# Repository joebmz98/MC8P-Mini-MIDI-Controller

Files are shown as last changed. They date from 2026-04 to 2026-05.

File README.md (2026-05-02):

# MC8P Mini MIDI Controller

---

# **8-Pot Mini MIDI Controller**

A compact, open-source MIDI controller with **8 potentiometers**, each with **fully assignable MIDI CCs**, built for **Arduino NANO R3/R4 (Rev1)** or the **Pro Micro (Rev2)**.

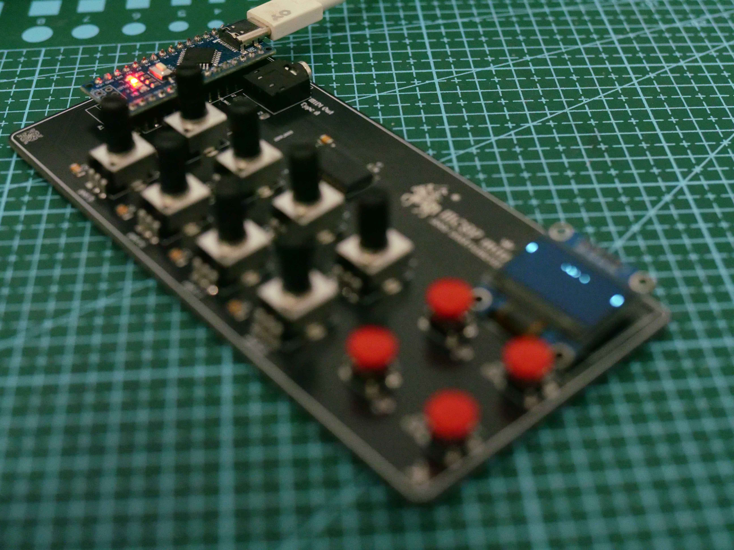
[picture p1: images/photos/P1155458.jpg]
Photo of the assembled MC8P mini MIDI Controller


---

## **Features**
- **8x Potentiometers** with smooth analog control via 16-channel MUX
- **Arduino NANO / Pro Micro (Rev2) Compatible** – Easy to source and program
- **SSD1306 I2C OLED (128x64)** for the UI
- **Per-Pot CC Assignment** – Full MIDI CC customization
- **4x Tactile Switches** for UI navigation/configuration
- **Standalone Operation** – No computer needed after setup
- **EEPROM Settings Storage** – Retains configurations after power-off
- **Temporary Override Mode** – Make temporary adjustments that snap back
- **MIDI over USB** (Pro Micro Rev ONLY) – Class-compliant, plug-and-play
- **Open-Source Firmware** (Arduino IDE-compatible)

---

## **Bill of Materials (BOM)**

| Component | Qty | Notes | Links / Part Numbers |
|---|-----|---|---|
| Arduino NANO / Pro Micro | 1 | Main microcontroller | [Arduino NANO R3](https://www.aliexpress.com/w/wholesale-arduino-nano.html?spm=a2g0o.productlist.search.0) / [Pro Micro](https://www.aliexpress.com/w/wholesale-pro-micro-arduino.html?spm=a2g0o.best.search.0) |
| 16-Channel MUX (74HC4067)  | 1 | For reading 8 potentiometers | [AliExpress](https://www.aliexpress.com/w/wholesale-cd74hc4067.html?spm=a2g0o.productlist.search.0) / CD74HC4067M96 (JLCPCB) |
| SSD1306 OLED (128×64) | 1 | I²C interface | [AliExpress](https://www.aliexpress.com/w/wholesale-ssd1306.html?spm=a2g0o.productlist.search.0) |
| B100K Potentiometers | 8 | Linear taper | [AliExpress](https://www.aliexpress.com/item/1005003523799166.html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"order"%3A"368"%2C"eval"%3A"1"%2C"fromPage"%3A"search"%7D&pdp_npi=6%40dis%21GBP%210.33%210.33%21%21%210.43%210.43%21%402151e6dc17777134792648341e4c8f%2112000026166615223%21sea%21UK%216042796089%21X%211%210%21n_tag%3A-29919%3Bd%3A582ad943%3Bm03_new_user%3A-29895&curPageLogUid=hZYrDWLC06u8&utparam-url=scene%3Asearch%7Cquery_from%3A%7Cx_object_id%3A1005003523799166%7C_p_origin_prod%3A&search_p4p_id=2026050202175910656752474918880005794025_1) |
| Tactile Switches | 4 | For menu navigation (ASSIGN, ENTER, PREV, NEXT) | K2-6639DP-B4SW-04 (JLCPCB) |
| 10k Resistors (SMD) | 7 | Pull-up for buttons and misc | 0603WAF1002T5E (JLCPCB) |
| 100nF SMD Capacitor | 1 | Power rail stabilisation | 1206B104K101CT (JLCPCB) |
| 10nF SMD Capacitors | 8 | Potentiometer filtering | 1206B103K500NT (JLCPCB) |
| 220Ω SMD Resistors | 2 | For MIDI circuitry | 0603WAF2200T5E (JLCPCB) |
| PJ307 Stereo Headphone Socket | 1 | 3.5mm MIDI TRS Out (Type A) | — |
| Reset Button (SMD) | 1 | Rev2 only - Reset button | KMR221GLFS (JLCPCB) |
| 0.1" Header Pins | 1 | For connecting components | — |
| PCB | 1 | Custom design | — |
| Potentiometer Knobs | 8 | For B100K potentiometers | — |

---

## **Available Purchase Options**
**DIY Kits** - Only NANO version (rev1) available → [**Purchase from my Tindie store**](https://www.tindie.com/stores/axsinstruments/)

---

## **Installation & Setup**
### **1. Flashing the Firmware**
- Install **Arduino IDE**
- Install required libraries (see Building from Source section)
- Open the `.ino` file in Arduino IDE | There are two files - one for NANO and one for Pro Micro
- Select your board (**Arduino NANO R3/R4 or ProMicro**)
- Upload the firmware

### **2. Hardware Assembly**
- Refer to the *Build Guide* (coming soon)

### **3. First Boot**
- Power via **USB** on the Arduino NANO
- Use the **OLED menu** to assign CCs

---

## **Configuration**

### Button Functions

| Button | Primary Function |
|---|---|
| ASSIGN | Enter/exit MIDI assignment menu |
| ENTER | Enter temporary override mode (hold), confirm selections |
| PREV | Decrease values, navigate up |
| NEXT | Increase values, navigate down |
| PREV + NEXT (hold 2 sec) | Factory reset |

### Screen Hierarchy

The interface is organized into two main screens:

**MAIN SCREEN** → **ASSIGN SCREEN** → parameter editing

### Main Screen

This is your default operating view. The screen displays:
- Current selected pot number (1-8)
- A horizontal bar graph showing the current MIDI value (0-127)
- The numeric MIDI value centered on screen

From the main screen:
- Press **ASSIGN** to enter the assign menu
- Press and hold **ENTER** to activate temporary override mode

### Temporary Override Mode

When you press and hold ENTER on the main screen, the controller enters temporary override mode:
- The display inverts as visual feedback
- All potentiometer adjustments override the stored values
- When you release ENTER, the controller:
  - Returns to the stored MIDI values
  - Activates catch-up mode
  - The display returns to normal

### Catch-Up Mode

After exiting temporary override mode, catch-up mode is activated:
- Potentiometers must pass through their stored position before taking control
- This prevents abrupt jumps in your MIDI parameters
- Once all pots have caught up, normal operation resumes

### Assign Screen (MIDI ASSIGN)

Press ASSIGN from the main screen to enter the configuration menu. Use PREV/NEXT to navigate through edit modes:

**Navigation flow:**
1. **SELECT POT** – Choose which pot (1-8) to configure
2. **EDIT CHANNEL** – Set MIDI channel (1-16) or OMNI
3. **EDIT CC** – Set Control Change number (0-127)
4. **EDIT MIN** – Minimum output value (0-127)
5. **EDIT MAX** – Maximum output value (0-127)
6. **EDIT DIR** – Normal (0-127) or Inverted (127-0)

**Editing values:**
- **PREV/NEXT** – Adjust values incrementally
- **Potentiometer 8** – Smooth continuous adjustment across full range - faster when selecting MIDI CC's and custom ranges
- **ENTER** – Cycle through edit modes
- **ASSIGN** – Save settings and return to main screen

### Factory Reset

From the main screen, press and hold **PREV + NEXT** for 2 seconds:
- All settings reset to defaults
- Device confirms reset on screen
- Resets to:
  - Channel 1-8 (one per pot)
  - CC 7 for all pots
  - Min 0, Max 127
  - Normal direction

---

## **MIDI Implementation**
- **USB MIDI** – Class-compliant in rev2, no drivers needed
- **Per-Pot Configuration** – Each pot has independent:
  - MIDI Channel (1-16 or OMNI)
  - CC Number (0-127)
  - Value Range (min/max 0-127)
  - Direction (Normal/Inverted)
- **EEPROM Storage** – Settings persist after power-off

---

## **Building from Source**
- Requires **Arduino IDE**
- Libraries:
  - `Adafruit_SSD1306` – OLED display driver
  - `Adafruit_GFX` – Graphics library for UI
  - `MIDI` – MIDI protocol handling
  - `EEPROM` – Settings storage (built-in)

---

## **Hardware Pin Connections**

| Component | Arduino NANO Pins |
|---|---|
| MUX SIG | A0 |
| MUX S0 | D8 |
| MUX S1 | D9 |
| MUX S2 | D10 |
| MUX S3 | D16 |
| ASSIGN Button | D4 (INPUT_PULLUP) |
| ENTER Button | D5 (INPUT_PULLUP) |
| PREV Button | D6 (INPUT_PULLUP) |
| NEXT Button | D7 (INPUT_PULLUP) |
| OLED SDA | D2 (SDA) |
| OLED SCL | D3 (SCL) |
| Pot 1-8 | MUX Channels 0-7 |

---

## **Differences from MC8P**

| Feature | MC8P (Teensy 4.0) | MC8P mini (Arduino) |
|---|---|---|
| Microcontroller | Teensy 4.0 | Arduino NANO / Pro Micro  |
| MIDI Output | USB + TRS 3.5mm | Rev1 TRS Only / Rev2 USB + TRS 3.5mm |
| Max CCs per Pot | Up to 10 | 1 |
| EEPROM | Yes | Yes |
| Catch-up Mode | Yes | Yes |
| Temp Override | Yes | Yes |

---

## **License**
**MIT License** – Open-source for personal & commercial use

---

## **Support & Contributions**
- **Issues:** Open a GitHub ticket
- **Custom Requests:** Start a thread in the discussions page or email: axs.instruments@gmail.com
- **Want to improve it?** PRs welcome!

---

## **Version History**
- **v1.0** – Initial release
  - 8-pot control via 74HC4067 MUX
  - Full MIDI CC assignment per pot
  - OLED UI with assign menu
  - EEPROM settings storage
  - Temporary override and catch-up modes
  - Factory reset function

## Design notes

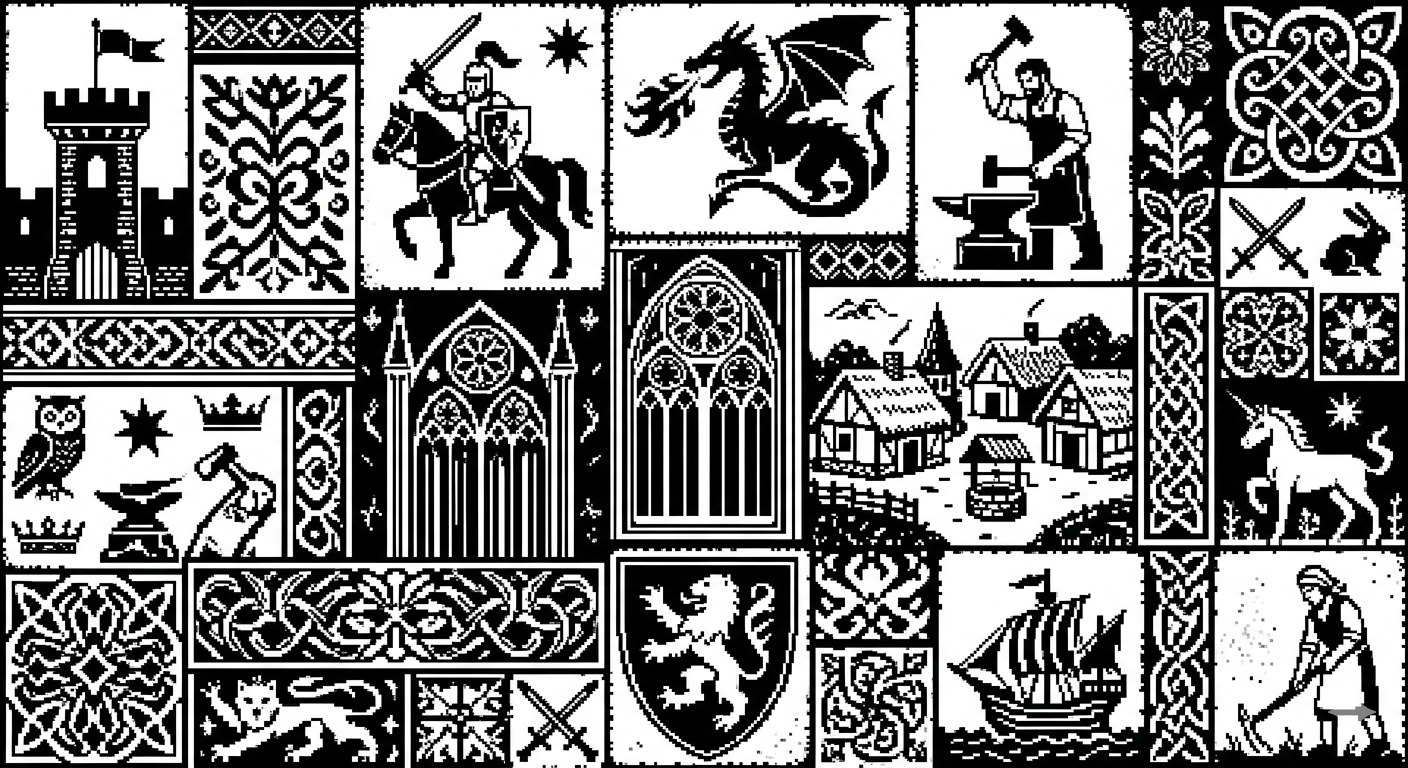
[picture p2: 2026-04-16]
images/references/Gemini_Generated_Image_kuhz5skuhz5skuhz.png

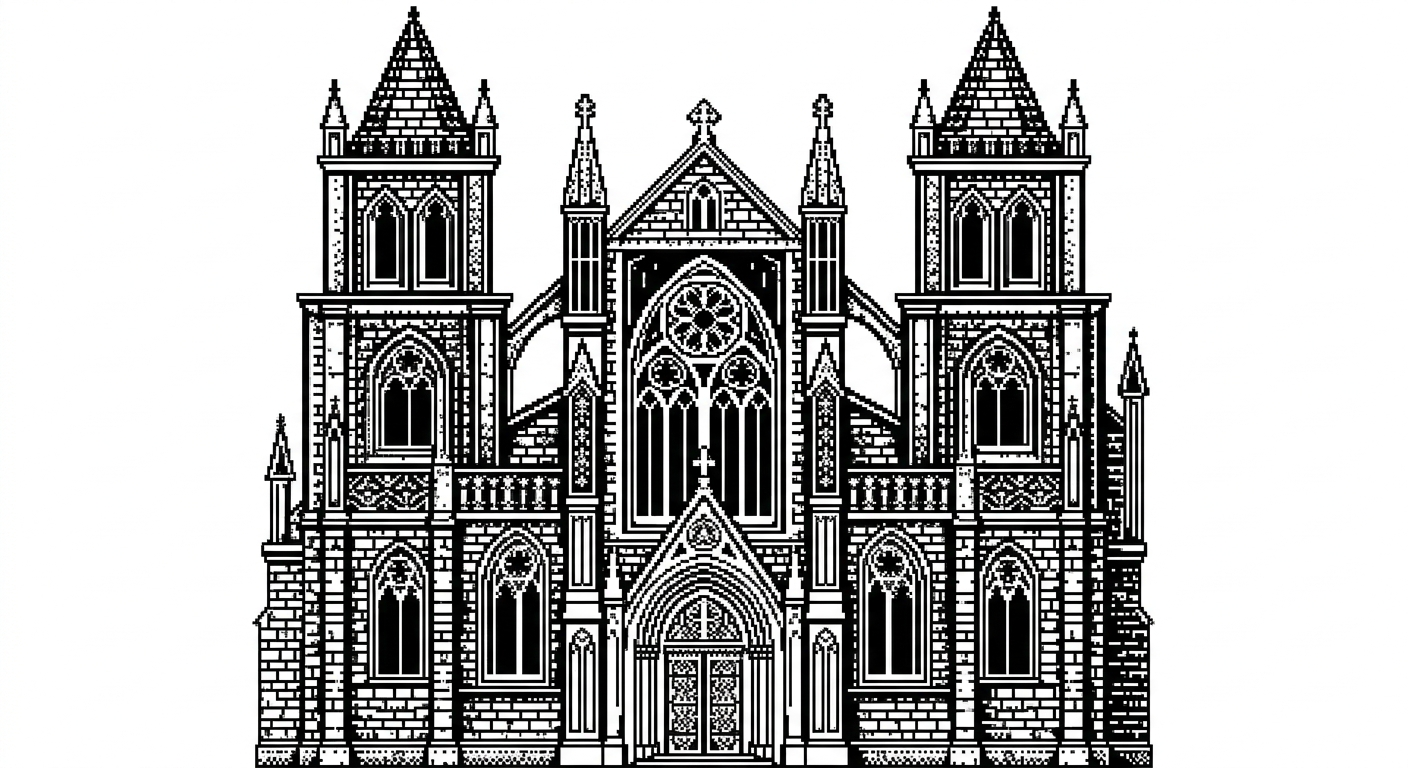
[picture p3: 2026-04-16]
images/references/Gemini_Generated_Image_gsy9jngsy9jngsy9.png

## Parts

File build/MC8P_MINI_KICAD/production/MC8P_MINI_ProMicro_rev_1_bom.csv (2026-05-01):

Designator | Footprint | Quantity | Value | LCSC Part #
BRD1 | 128x64OLED | 1 | SSD1306
C1, C2, C3, C4, C5, C6, C7, C8 | 1206 | 8 | 10nF
C9 | 1206 | 1 | 100nF_0603_16V
J1 | Jack_3.5mm_CUI_SJ1-3525N_Horizontal | 1 | AudioJack3
R1, R2 | R_0603 | 2 | 220R_0603
R3, R4, R5, R6, R7, R8, R9 | R_0603 | 7 | 10k_0402
RV1, RV2, RV3, RV4, RV5, RV6, RV7, RV8 | Potentiometer_RV09 | 8 | 10k
SW1 | SW_PUSH_6mm | 1 | ASSIGN
SW2 | SW_PUSH_6mm | 1 | ENTER
SW3 | SW_PUSH_6mm | 1 | PREV
SW4 | SW_PUSH_6mm | 1 | NEXT
SW5 | SW_Push_1P1T_NO_CK_KMR2 | 1 | RESET
U1 | SOIC-24W_7.5x15.4mm_P1.27mm | 1 | CD74HC4067M
U2 | ProMicro | 1 | ProMicro

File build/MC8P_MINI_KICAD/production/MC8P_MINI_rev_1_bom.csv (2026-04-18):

Designator | Footprint | Quantity | Value | LCSC Part #
C1, C2, C3, C4, C5, C6, C7, C8 | 1206 | 8 | 10nF
C9 | 1206 | 1 | 100nF_0603_16V
R1, R2 | R_0603 | 2 | 220R_0603
R3, R4, R5, R6, R7, R8, R9 | R_0603 | 7 | 10k_0402
SW1 | SW_PUSH_6mm | 1 | ASSIGN
SW2 | SW_PUSH_6mm | 1 | ENTER
SW3 | SW_PUSH_6mm | 1 | PREV
SW4 | SW_PUSH_6mm | 1 | NEXT
U1 | SOIC-24W_7.5x15.4mm_P1.27mm | 1 | CD74HC4067M

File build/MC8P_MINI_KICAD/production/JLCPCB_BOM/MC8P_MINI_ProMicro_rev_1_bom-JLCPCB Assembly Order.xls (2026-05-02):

JLCPCB BOM Tool - BOM Matching
BOM name：MC8P_MINI_ProMicro_rev_1_bom-JLCPCB Assembly Order.xlsx |  |  | Download Time：2026-05-02 15:24:44 |  |  |  | * Our matching results are updated in real-time, but stock and prices may change. If it's been over 24 hours, please re-match before placing your order.
PCB Assembled Qty：5 |  |  | Est. Total Price：13.3406
Your BOM |  |  |  |  | Matched Parts |  |  |  |  |  |  | Order Information
Top Designator | Bottom Designator | Comment | Footprint | JLCPCB Part # | Matches | Part # | Manufacturer | Footprint | Description | Category | Warning | JLCPCB Part # | Product link | Lib Type | Qty | Source | Total Price ($)
C1,C2,C3,C4,C5,C6,C7,C8 |  | 10nF | 1206 |  | Select by System | 1206B103K500NT | FH (Guangdong Fenghua Advanced Tech) | 1206 | 10nF 50V X7R ±10% 1206 Multilayer Ceramic Capacitors MLCC - SMD/SMT ROHS | Multilayer Ceramic Capacitors MLCC - SMD/SMT |  | C1846 | https://jlcpcb.com/partdetail/2198-1206B103K500NT/C1846 | Basic | 40 | 40 JLCPCB | 0.54
C9 |  | 100nF_0603_16V | 1206 |  | Select by Customer | 1206B104K101CT | Walsin Tech Corp | 1206 | 100V 100nF X7R ±10% 1206 Multilayer Ceramic Capacitors MLCC - SMD/SMT ROHS | Multilayer Ceramic Capacitors MLCC - SMD/SMT |  | C77502 | https://jlcpcb.com/partdetail/Walsin_TechCorp-1206B104K101CT/C77502 | Extended | 15 | 15 JLCPCB | 0.1815
R1,R2 |  | 220R_0603 | R_0603 |  | Select by Customer | 0603WAF2200T5E | UNI-ROYAL(Uniroyal Elec) | 0603 | -55℃~+155℃ 100mW 220Ω 75V Thick Film Resistor ±1% ±100ppm/℃ 0603 Chip Resistor - Surface Mount ROHS | Chip Resistor - Surface Mount | 1.The comment (0603WAF2200T5E) of this part does not match the one (220R_0603) provided in your BOM. Please confirm; | C22962 | https://jlcpcb.com/partdetail/23689-0603WAF2200T5E/C22962 | Basic | 10 | 10 JLCPCB | 0.015
R3,R4,R5,R6,R7,R8,R9 |  | 10k_0402 | R_0603 |  | Select by Customer | 0603WAF1002T5E | UNI-ROYAL(Uniroyal Elec) | 0603 | -55℃~+155℃ 100mW 10kΩ 75V Thick Film Resistor ±1% ±100ppm/℃ 0603 Chip Resistor - Surface Mount ROHS | Chip Resistor - Surface Mount | 1.The comment (0603WAF1002T5E) of this part does not match the one (10k_0402) provided in your BOM. Please confirm; | C25804 | https://jlcpcb.com/partdetail/26547-0603WAF1002T5E/C25804 | Basic | 35 | 35 JLCPCB | 0.049
SW1 |  | ASSIGN | SW_PUSH_6mm |  | Select by Customer | K2-6639DP-B4SW-04 | Korean Hroparts Elec | 插件-4P,6x6mm | -25℃~+85℃ 1,000,000 cycles 12V 2.5N 4.5mm 50mA 6mm 6mm Round Button SPST Through Hole 插件-4P,6x6mm Tactile Switches ROHS | Tactile Switches | 1.Multiple lines in the BOM have been matched to the same part. Please check if the matching is correct. ; | C83205 | https://jlcpcb.com/partdetail/Korean_HropartsElec-K2_6639DP_B4SW04/C83205 | Extended | 21 | 21 JLCPCB | 0.9639
SW2 |  | ENTER | SW_PUSH_6mm |  | Select by Customer | K2-6639DP-B4SW-04 | Korean Hroparts Elec | 插件-4P,6x6mm | -25℃~+85℃ 1,000,000 cycles 12V 2.5N 4.5mm 50mA 6mm 6mm Round Button SPST Through Hole 插件-4P,6x6mm Tactile Switches ROHS | Tactile Switches | 1.Multiple lines in the BOM have been matched to the same part. Please check if the matching is correct. ; | C83205 | https://jlcpcb.com/partdetail/Korean_HropartsElec-K2_6639DP_B4SW04/C83205 | Extended | 21 | 21 JLCPCB | 0.9639
SW3 |  | PREV | SW_PUSH_6mm |  | Select by Customer | K2-6639DP-B4SW-04 | Korean Hroparts Elec | 插件-4P,6x6mm | -25℃~+85℃ 1,000,000 cycles 12V 2.5N 4.5mm 50mA 6mm 6mm Round Button SPST Through Hole 插件-4P,6x6mm Tactile Switches ROHS | Tactile Switches | 1.Multiple lines in the BOM have been matched to the same part. Please check if the matching is correct. ; | C83205 | https://jlcpcb.com/partdetail/Korean_HropartsElec-K2_6639DP_B4SW04/C83205 | Extended | 21 | 21 JLCPCB | 0.9639
SW4 |  | NEXT | SW_PUSH_6mm |  | Select by Customer | K2-6639DP-B4SW-04 | Korean Hroparts Elec | 插件-4P,6x6mm | -25℃~+85℃ 1,000,000 cycles 12V 2.5N 4.5mm 50mA 6mm 6mm Round Button SPST Through Hole 插件-4P,6x6mm Tactile Switches ROHS | Tactile Switches | 1.Multiple lines in the BOM have been matched to the same part. Please check if the matching is correct. ; | C83205 | https://jlcpcb.com/partdetail/Korean_HropartsElec-K2_6639DP_B4SW04/C83205 | Extended | 21 | 21 JLCPCB | 0.9639
SW5 |  | RESET | SW_Push_1P1T_NO_CK_KMR2 |  | Select by Customer | KMR221GLFS | C&K | SMD,4.6x2.8mm | -40℃~+85℃ 1.9mm 2.8mm 2N 32V 4.6mm 50mA Gull Wing Round Button SPST Surface Mount,Vertical SMD,4.6x2.8mm Tactile Switches ROHS | Tactile Switches | 1.The comment (KMR221GLFS) of this part does not match the one (RESET) provided in your BOM. Please confirm; | C72443 | https://jlcpcb.com/partdetail/CK-KMR221GLFS/C72443 | Extended | 5 | 5 JLCPCB | 3.8585
U1 |  | CD74HC4067M | SOIC-24W_7.5x15.4mm_P1.27mm |  | Select by Customer | CD74HC4067M96 | Texas Instruments | SOIC-24-300mil | -55℃~+125℃ 15ns 2V~6V 70Ω 83ns 83ns 89MHz SOIC-24-300mil Analog Switches, Multiplexers ROHS | Analog Switches, Multiplexers | 1.The comment (CD74HC4067M96) of this part does not match the one (CD74HC4067M) provided in your BOM. Please confirm; | C496123 | https://jlcpcb.com/partdetail/TexasInstruments-CD74HC4067M96/C496123 | Extended | 5 | 5 JLCPCB | 4.841

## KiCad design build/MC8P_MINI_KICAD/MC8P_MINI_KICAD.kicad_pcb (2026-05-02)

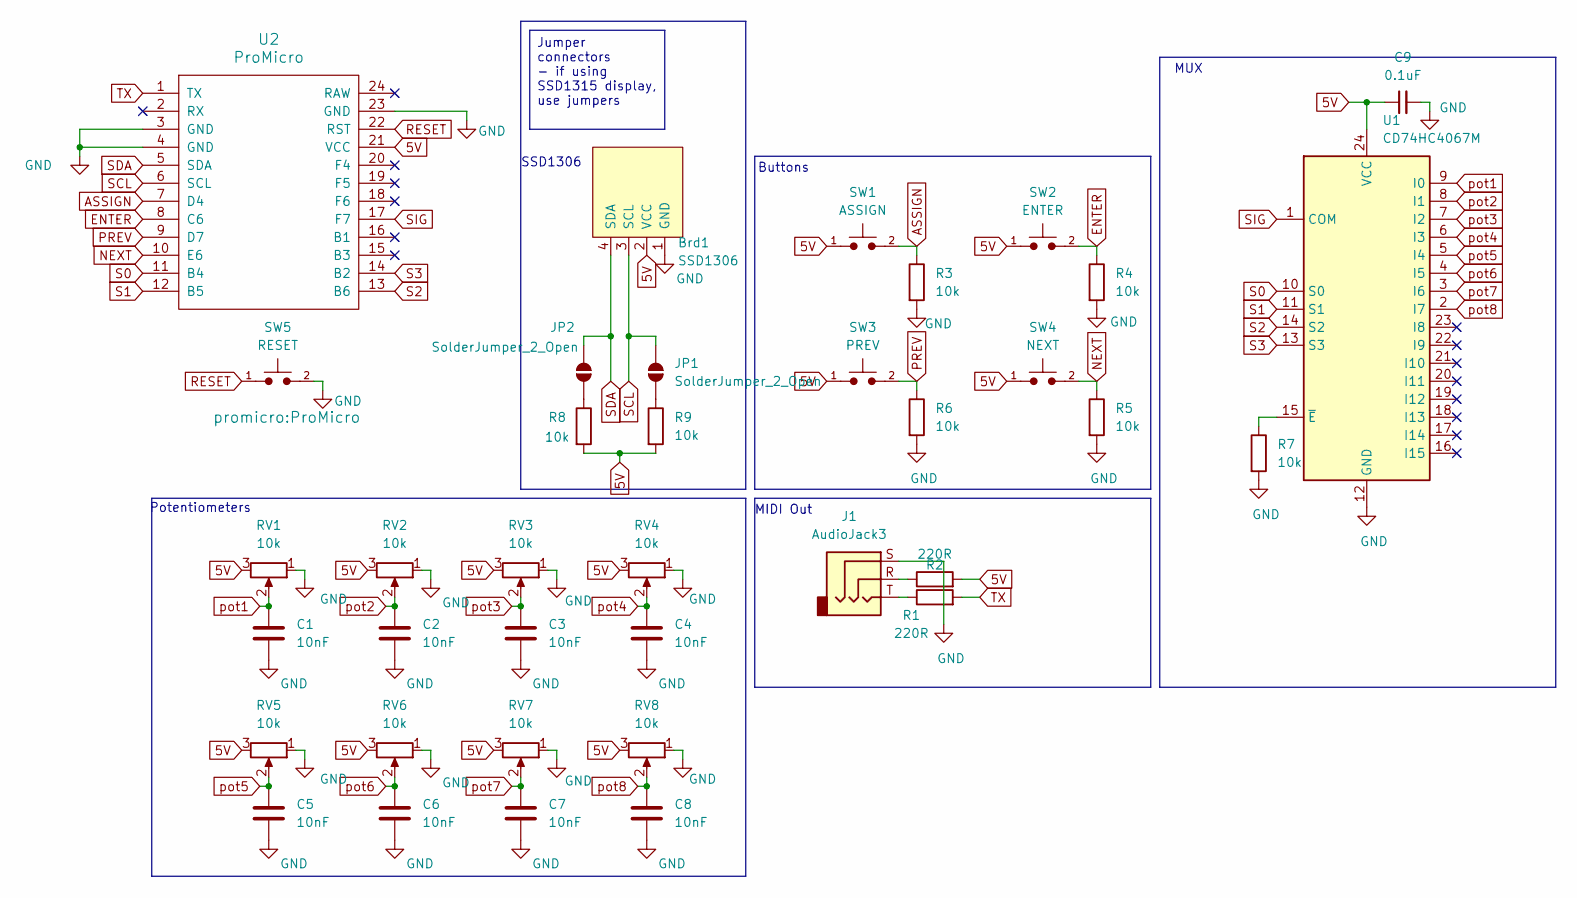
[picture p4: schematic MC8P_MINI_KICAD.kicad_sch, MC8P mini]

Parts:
Brd1: SSD1306; 128x64OLED
C1, C2, C3, C4, C5, C6, C7, C8: 10nF; C_1206_3216Metric
C9: 100nF_0603_16V; C_1206_3216Metric; Part Number 0603YC104KAT2A; JLCPCB ID C14663
J1: AudioJack3; Jack_3.5mm_CUI_SJ1-3525N_Horizontal
JP1, JP2: SolderJumper_2_Open; SolderJumper-2_P1.3mm_Open_RoundedPad1.0x1.5mm
R1, R2: 220R_0603; R_0603; Part Number RC0603FR-07220RL; JLCPCB ID C8218
R3, R4, R5, R6, R7, R8, R9: 10k_0402; R_0603; Part Number RT0402FRE0710KL
RV1, RV2, RV3, RV4, RV5, RV6, RV7, RV8: 10k; Potentiometer_RV09
SW1: ASSIGN; SW_PUSH_6mm
SW2: ENTER; SW_PUSH_6mm
SW3: PREV; SW_PUSH_6mm
SW4: NEXT; SW_PUSH_6mm
SW5: RESET; SW_Push_1P1T_NO_CK_KMR2
U1: CD74HC4067M; SOIC-24W_7.5x15.4mm_P1.27mm
U2: ProMicro

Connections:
5V: Brd1.2 (VCC), C9.1, R2.2, R8.2, R9.2, RV1.3, RV2.3, RV3.3, RV4.3, RV5.3, RV6.3, RV7.3, RV8.3, SW1.1, SW2.1, SW3.1, SW4.1, U1.24 (VCC), U2.21 (VCC)
ASSIGN: R3.1, SW1.2, U2.7 (D4)
ENTER: R4.1, SW2.2, U2.8 (C6)
GND: Brd1.1 (GND), C1.1, C2.1, C3.1, C4.1, C5.1, C6.1, C7.1, C8.1, C9.2, J1.S, R3.2, R4.2, R5.2, R6.2, R7.2, RV1.1, RV2.1, RV3.1, RV4.1, RV5.1, RV6.1, RV7.1, RV8.1, SW5.2, U1.12 (GND), U2.3 (GND), U2.4 (GND), U2.23 (GND)
NEXT: R5.1, SW4.2, U2.10 (E6)
unnamed: J1.R, R2.1
unnamed: J1.T, R1.1
unnamed: JP1.1 (A), R9.1
unnamed: JP2.1 (A), R8.1
unnamed: R7.1, U1.15 (~E)
PREV: R6.1, SW3.2, U2.9 (D7)
RESET: SW5.1, U2.22 (RST)
S0: U1.10 (S0), U2.11 (B4)
S1: U1.11 (S1), U2.12 (B5)
S2: U1.14 (S2), U2.13 (B6)
S3: U1.13 (S3), U2.14 (B2)
SCL: Brd1.3 (SCL), JP1.2 (B), U2.6 (SCL)
SDA: Brd1.4 (SDA), JP2.2 (B), U2.5 (SDA)
SIG: U1.1 (COM), U2.17 (F7)
TX: R1.2, U2.1 (TX)
pot1: C1.2, RV1.2, U1.9 (I0)
pot2: C2.2, RV2.2, U1.8 (I1)
pot3: C3.2, RV3.2, U1.7 (I2)
pot4: C4.2, RV4.2, U1.6 (I3)
pot5: C5.2, RV5.2, U1.5 (I4)
pot6: C6.2, RV6.2, U1.4 (I5)
pot7: C7.2, RV7.2, U1.3 (I6)
pot8: C8.2, RV8.2, U1.2 (I7)

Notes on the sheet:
MIDI Out
Potentiometers
Buttons
MUX
SSD1306
Jumper connectors - if using SSD1315 display, use jumpers

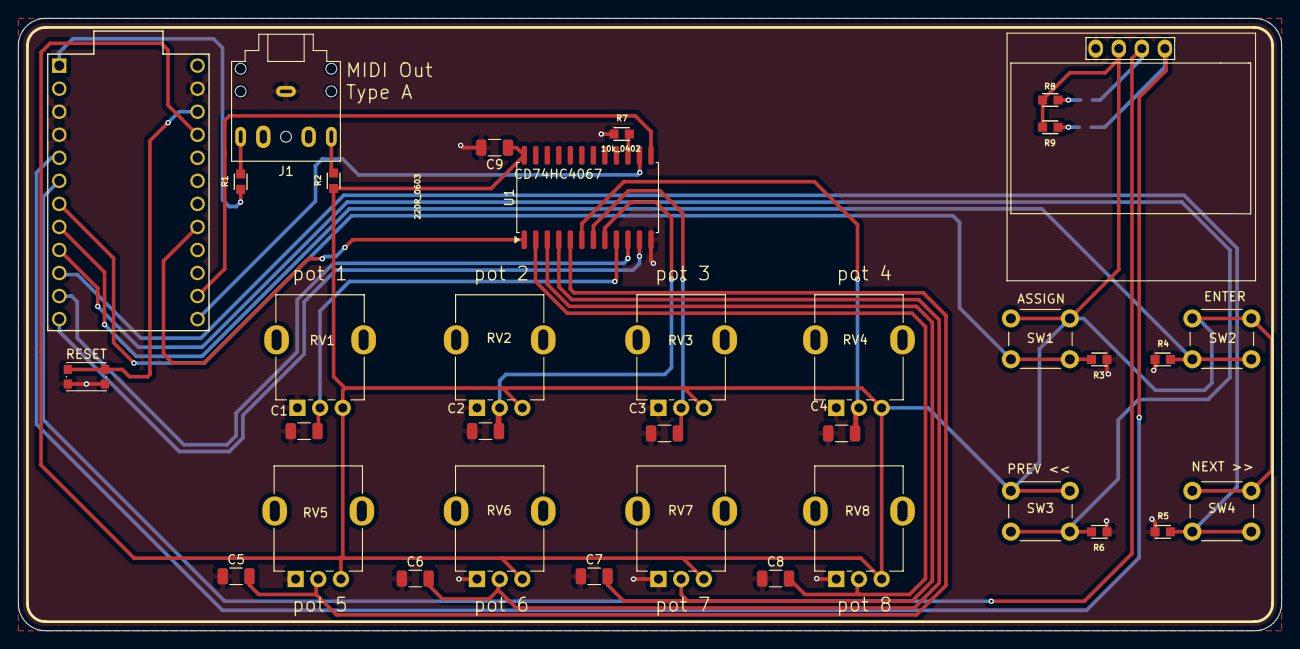
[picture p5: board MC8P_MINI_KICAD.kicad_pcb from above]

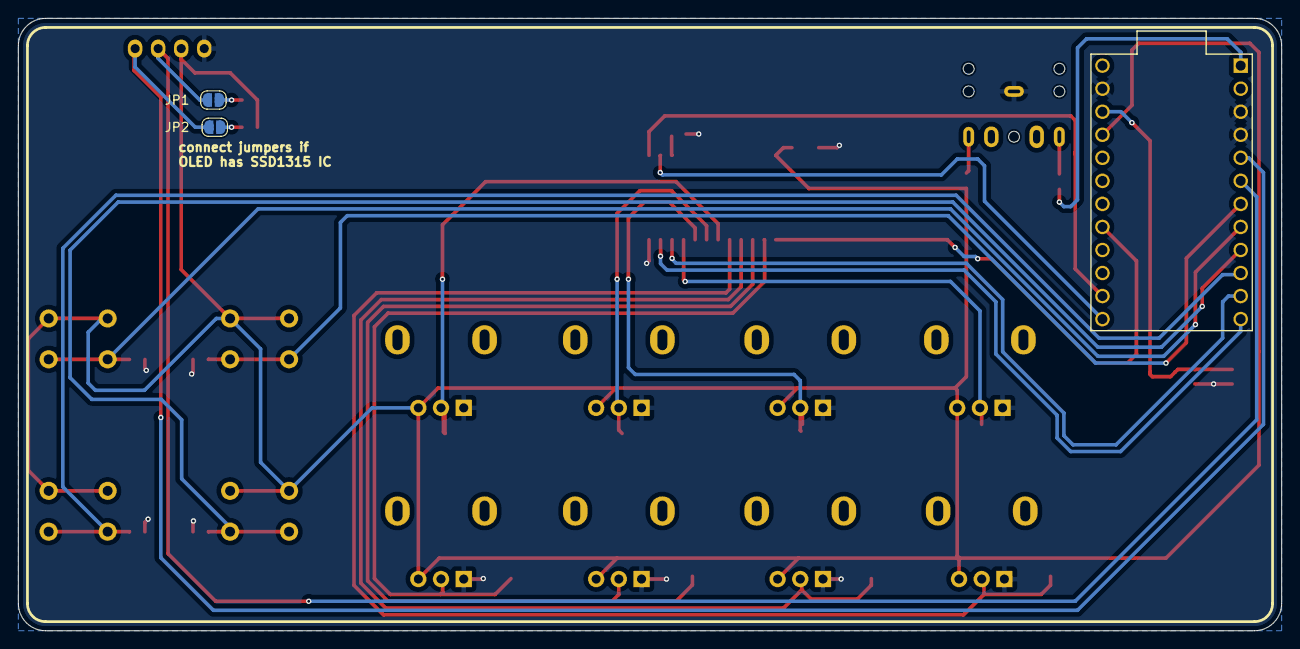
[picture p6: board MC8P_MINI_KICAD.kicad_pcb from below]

Board: 2 copper layers, 139.2 x 67.5 mm, 37 parts (2 on the bottom side), 28 nets.

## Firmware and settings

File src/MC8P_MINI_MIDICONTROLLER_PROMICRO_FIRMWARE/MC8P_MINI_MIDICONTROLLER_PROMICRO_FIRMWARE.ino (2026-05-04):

// ********************* //
// MC8P mini             //
// MIDI Controller       //
// firmware version 1.0  //
// ********************* //
// controller by         //
// .axs instruments      //
// ********************* //

// -- LIBRARIES --
#include <Adafruit_SSD1306.h>
#include <Adafruit_GFX.h>
#include <MIDI.h>
#include <MIDIUSB.h>
#include <Wire.h>
#include <EEPROM.h>
#include "usb_rename.h"

// -- OLED SETUP --
#define SCREEN_WIDTH 128
#define SCREEN_HEIGHT 64
#define SCREEN_ADDRESS 0x3C
#define OLED_RESET -1
Adafruit_SSD1306 display(SCREEN_WIDTH, SCREEN_HEIGHT, &Wire, OLED_RESET);

// -- MUX --
#define MUX_SIG A0
#define MUX_S0 8
#define MUX_S1 9
#define MUX_S2 10
#define MUX_S3 16

// -- POTS --
// -- POTS ARE CONNECTED TO MUX
#define POT_1 0
#define POT_2 1
#define POT_3 2
#define POT_4 3
#define POT_5 4
#define POT_6 5
#define POT_7 6
#define POT_8 7

// -- BUTTONS --
#define ASSIGN_BUTTON 4
#define ENTER_BUTTON 5
#define PREV_BUTTON 6
#define NEXT_BUTTON 7

// -- EEPROM --
const int EEPROM_ADDRESS = 0;

// -- MIDI INSTANCE --
MIDI_CREATE_INSTANCE(HardwareSerial, Serial1, MIDI_DIN);

// -- MIDI STRUCT
struct MIDIMessage {
  uint8_t cc = 7;
  uint8_t channel = 1;
  bool omni = false;
  uint8_t minValue = 0;
  uint8_t maxValue = 127;
  bool isInverted = false;
};

MIDIMessage potMessages[8];

// -- USB DESCRIPTOR --
USBRename deviceName = USBRename("MC8P Mini", ".axs instruments", NULL);

// -- FIRMWARE VERSION --
//const char FIRMWARE_VERSION[] = "1.0";  // FOR NANO R4
const char FIRMWARE_VERSION[] PROGMEM = "1.0";  // USE WITH NANO R3

// -- VARIABLES --
uint16_t lastRawValues[8] = { 0, 0, 0, 0, 0, 0, 0, 0 };
uint8_t lastMidiValues[8] = { 0, 0, 0, 0, 0, 0, 0, 0 };
uint8_t lastEditedPot = 0;
unsigned long lastPotReadTime = 0;
const unsigned long readDelay = 5;

// Fixed threshold for stability (2% of 127 = ~3)
const uint8_t CHANGE_THRESHOLD = 2;

// -- SCREENS --
enum ScreenState { MAIN_SCREEN,
                   ASSIGN_SCREEN };
ScreenState currentScreen = MAIN_SCREEN;

// -- ASSIGN SCREEN VARIABLES --
uint8_t selectedPot = 0;
uint8_t assignEditMode = 0;
unsigned long lastFlashTime = 0;
const unsigned long flashInterval = 500;
bool showPotNumber = true;

// -- BUTTON DEBOUNCING --
unsigned long lastButtonPressTime = 0;
const unsigned long buttonDebounceDelay = 100;
bool lastAssignButtonState = HIGH;
bool lastEnterButtonState = HIGH;
bool lastPrevButtonState = HIGH;
bool lastNextButtonState = HIGH;
unsigned long bothButtonsPressTime = 0;
bool bothButtonsHeld = false;

// -- TEMP MODE VARIABLES --
bool tempModeActive = false;
uint8_t storedMidiValues[8];  // Store original values when entering temp mode
bool catchupModeActive = false;

// -- USB STATUS -- 

// -- EEPROM FUNCTIONS --
// -- SAVE EEPROM
void saveSettings() {
  EEPROM.put(EEPROM_ADDRESS, potMessages);
}

// -- LOAD FROM EEPROM
void loadSettings() {
  // We read the data into our array
  EEPROM.get(EEPROM_ADDRESS, potMessages);

  // Sanity Check: If EEPROM is empty (new chip), it returns 255.
  // We check if the first channel is within valid range (1-16) or OMNI.
  // If not, we reset to defaults to avoid weird behavior.
  if (potMessages[0].channel > 16 && !potMessages[0].omni) {
    for (int i = 0; i < 8; i++) {
      potMessages[i].cc = 7;
      potMessages[i].channel = i + 1;
      potMessages[i].omni = false;
      potMessages[i].minValue = 0;
      potMessages[i].maxValue = 127;
      potMessages[i].isInverted = false;
    }
    saveSettings();  // Save these defaults
  }
}

// -- FUNCTION TO READ MUX CHANNEL --
int readMUXChannel(int channel) {
  digitalWrite(MUX_S0, channel & 1);
  digitalWrite(MUX_S1, (channel >> 1) & 1);
  digitalWrite(MUX_S2, (channel >> 2) & 1);
  digitalWrite(MUX_S3, (channel >> 3) & 1);
  delayMicroseconds(50);  // up from 10 — gives MUX more settling time
  // Take 4 readings and average to reduce ADC noise
  int sum = 0;
  for (int i = 0; i < 4; i++) {
    sum += analogRead(MUX_SIG);
  }
  return sum >> 2;  // divide by 4
}

// -- FUNCTION TO MAP RAW VALUE TO MIDI VALUE --
int mapRawToMIDI(int potNumber, int rawValue) {
  uint8_t minVal = potMessages[potNumber].minValue;
  uint8_t maxVal = potMessages[potNumber].maxValue;

  // Ensure min is less than max
  if (minVal > maxVal) {
    uint8_t temp = minVal;
    minVal = maxVal;
    maxVal = temp;
  }

  int mappedValue;
  if (potMessages[potNumber].isInverted) {
    mappedValue = map(rawValue, 0, 1023, maxVal, minVal);
  } else {
    mappedValue = map(rawValue, 0, 1023, minVal, maxVal);
  }

  return constrain(mappedValue, 0, 127);
}

// -- FUNCTION TO SEND MIDI CC MESSAGE (USB + DIN) --
void sendMIDICC(int potNumber, int midiValue) {
  uint8_t cc = potMessages[potNumber].cc;
  uint8_t chan = potMessages[potNumber].channel;
  uint8_t channelZeroBased = chan - 1;

  // Only send USB MIDI if a host is connected and configured
    bool usbReady = USBDevice.configured() && (millis() > 3000);

  if (potMessages[potNumber].omni) {
    for (int ch = 1; ch <= 16; ch++) {
      MIDI_DIN.sendControlChange(cc, midiValue, ch);
      if (usbReady) {
        midiEventPacket_t usbEvent = { 0x0B, 0xB0 | (ch - 1), cc, (uint8_t)midiValue };
        MidiUSB.sendMIDI(usbEvent);
      }
    }
  } else {
    MIDI_DIN.sendControlChange(cc, midiValue, chan);
    if (usbReady) {
      midiEventPacket_t usbEvent = { 0x0B, 0xB0 | channelZeroBased, cc, (uint8_t)midiValue };
      MidiUSB.sendMIDI(usbEvent);
    }
  }

  if (usbReady) {
    MidiUSB.flush();
  }
}

// -- FUNCTION TO ENTER TEMP MODE --
void enterTempMode() {
  if (!tempModeActive && currentScreen == MAIN_SCREEN) {
    tempModeActive = true;

    // Store the current MIDI values (these are the values we'll return to)
    for (int i = 0; i < 8; i++) {
      storedMidiValues[i] = lastMidiValues[i];
    }

    // Also store the current raw values to know where the pots physically are
    for (int i = 0; i < 8; i++) {
      lastRawValues[i] = readMUXChannel(i);
    }

    // Invert display for visual feedback
    display.invertDisplay(true);
  }
}

// -- FUNCTION TO EXIT TEMP MODE --
void exitTempMode() {
  if (tempModeActive) {
    tempModeActive = false;

    // Activate catch-up mode
    catchupModeActive = true;

    // Restore display
    display.invertDisplay(false);

    // Force lastMidiValues to the stored values (what we want to return to)
    // This ensures the display shows the target values
    for (int i = 0; i < 8; i++) {
      lastMidiValues[i] = storedMidiValues[i];
    }

    // Send the stored MIDI values immediately (this jumps back to original state)
    for (int i = 0; i < 8; i++) {
      sendMIDICC(i, storedMidiValues[i]);
    }

    // Redraw main screen with the stored values
    drawMainScreen(lastEditedPot, lastMidiValues[lastEditedPot]);
  }
}

// -- FUNCTION TO HANDLE CATCH-UP AFTER TEMP MODE --
void handleCatchup() {
  if (!catchupModeActive) return;

  bool allCaughtUp = true;

  // Check each pot to see if it's caught up to its stored value
  for (int i = 0; i < 8; i++) {
    // Read the current physical position of the pot
    int rawValue = readMUXChannel(i);
    int currentPhysicalValue = mapRawToMIDI(i, rawValue);
    int targetValue = storedMidiValues[i];

    // Has the physical pot reached the target value?
    bool hasReachedTarget = false;

    // Check if the physical pot position matches the target value
    // We need to allow for a small tolerance because of analog readings
    if (abs(currentPhysicalValue - targetValue) <= CHANGE_THRESHOLD) {
      hasReachedTarget = true;
    }

    if (hasReachedTarget) {
      // This pot has caught up - update lastMidiValues to the physical value
      lastMidiValues[i] = currentPhysicalValue;
      lastRawValues[i] = rawValue;

      // Send the current MIDI value (which is now the target value)
      sendMIDICC(i, currentPhysicalValue);

      // Update display if this is the last edited pot
      if (i == lastEditedPot && currentScreen == MAIN_SCREEN) {
        drawMainScreen(lastEditedPot, lastMidiValues[lastEditedPot]);
      }
    } else {
      // This pot hasn't caught up yet
      allCaughtUp = false;

      // IMPORTANT: Force lastMidiValues[i] to stay at the target value
      // This prevents any MIDI messages from being sent while in catch-up mode
      if (lastMidiValues[i] != targetValue) {
        lastMidiValues[i] = targetValue;
      }
    }
  }

  // If all pots have caught up, exit catch-up mode
  if (allCaughtUp) {
    catchupModeActive = false;
  }
}

// -- FACTORY RESET FUNCTION --
void factoryReset() {
  display.clearDisplay();
  display.setTextSize(1);
  display.setCursor(35, 28);
  display.print(F("MIDI reset"));
  display.display();

  for (int i = 0; i < 8; i++) {
    potMessages[i].cc = 7;
    potMessages[i].channel = i + 1;
    potMessages[i].omni = false;
    potMessages[i].minValue = 0;
    potMessages[i].maxValue = 127;
    potMessages[i].isInverted = false;
  }
  saveSettings();

  // Reset last MIDI values to match new settings
  for (int i = 0; i < 8; i++) {
    int rawValue = readMUXChannel(i);
    lastRawValues[i] = rawValue;
    lastMidiValues[i] = mapRawToMIDI(i, rawValue);
    sendMIDICC(i, lastMidiValues[i]);
  }

  delay(1500);
  currentScreen = MAIN_SCREEN;
  drawMainScreen(lastEditedPot, lastMidiValues[lastEditedPot]);
}

// -- FUNCTION FOR BUTTON HANDLING --
void readButtons() {
  unsigned long currentTime = millis();

  bool assignButtonState = digitalRead(ASSIGN_BUTTON);
  bool enterButtonState = digitalRead(ENTER_BUTTON);
  bool prevButtonState = digitalRead(PREV_BUTTON);
  bool nextButtonState = digitalRead(NEXT_BUTTON);

  // Check for both PREV and NEXT buttons held in MAIN screen
  if (currentScreen == MAIN_SCREEN && prevButtonState == HIGH && nextButtonState == HIGH) {
    if (!bothButtonsHeld) {
      bothButtonsPressTime = currentTime;
      bothButtonsHeld = true;
    } else if ((currentTime - bothButtonsPressTime) >= 2000) {
      // Both buttons held for 2 seconds - perform factory reset
      factoryReset();
      bothButtonsHeld = false;
      lastButtonPressTime = currentTime;
      // Reset button states to prevent immediate re-triggering
      lastPrevButtonState = prevButtonState;
      lastNextButtonState = nextButtonState;
      return;
    }
  } else {
    bothButtonsHeld = false;
  }

  // ASSIGN BUTTON
  if (assignButtonState == LOW && lastAssignButtonState == HIGH) {
    if ((currentTime - lastButtonPressTime) > buttonDebounceDelay) {
      if (currentScreen == MAIN_SCREEN) {
        currentScreen = ASSIGN_SCREEN;
        selectedPot = lastEditedPot;
        assignEditMode = 0;
        lastFlashTime = currentTime;
        //Serial.println("-- ASSIGN_BUTTON PRESSED >> Moving to ASSIGN_SCREEN");
        drawAssignScreen();
      } else {
        saveSettings();  // SAVE ON EXIT
        currentScreen = MAIN_SCREEN;
        //Serial.println("-- ASSIGN_BUTTON PRESSED >> Moving to MAIN_SCREEN");
        drawMainScreen(lastEditedPot, lastMidiValues[lastEditedPot]);
      }
      lastButtonPressTime = currentTime;
    }
  }
  lastAssignButtonState = assignButtonState;

  // ENTER BUTTON
  if (enterButtonState == HIGH && lastEnterButtonState == LOW) {
    if ((currentTime - lastButtonPressTime) > buttonDebounceDelay) {
      if (currentScreen == ASSIGN_SCREEN) {
        assignEditMode = (assignEditMode + 1) % 6;
        drawAssignScreen();
      } else if (currentScreen == MAIN_SCREEN) {
        //Serial.println(F("-- ENTER BUTTON HELD >> ACTIVATING TEMP MODE"));
        enterTempMode();
      }
      lastButtonPressTime = currentTime;
    }
  }

  if (enterButtonState == LOW && lastEnterButtonState == HIGH) {
    if (currentScreen == MAIN_SCREEN && tempModeActive) {
      //Serial.println(F("-- ENTER BUTTON RELEASED >> EXITING TEMP MODE"));
      exitTempMode();
    }
  }

  lastEnterButtonState = enterButtonState;

  // Only process other buttons in ASSIGN_SCREEN
  if (currentScreen != ASSIGN_SCREEN) {
    lastPrevButtonState = prevButtonState;
    lastNextButtonState = nextButtonState;
    return;
  }

  // PREV BUTTON
  if (prevButtonState == LOW && lastPrevButtonState == HIGH) {
    if ((currentTime - lastButtonPressTime) > buttonDebounceDelay) {
      if (assignEditMode == 0) {
        selectedPot = (selectedPot - 1 + 8) % 8;
        drawAssignScreen();
      } else if (assignEditMode == 1) {
        if (potMessages[selectedPot].omni) {
          potMessages[selectedPot].omni = false;
          potMessages[selectedPot].channel = 16;
        } else {
          if (potMessages[selectedPot].channel > 1) {
            potMessages[selectedPot].channel--;
          } else {
            potMessages[selectedPot].omni = true;
          }
        }
        drawAssignScreen();
      } else if (assignEditMode == 2) {
        if (potMessages[selectedPot].cc > 0) {
          potMessages[selectedPot].cc--;
        } else {
          potMessages[selectedPot].cc = 127;
        }
        drawAssignScreen();
      } else if (assignEditMode == 3) {
        if (potMessages[selectedPot].minValue > 0) {
          potMessages[selectedPot].minValue--;
        } else {
          potMessages[selectedPot].minValue = 127;
        }
        drawAssignScreen();
      } else if (assignEditMode == 4) {
        if (potMessages[selectedPot].maxValue > 0) {
          potMessages[selectedPot].maxValue--;
        } else {
          potMessages[selectedPot].maxValue = 127;
        }
        drawAssignScreen();
      } else if (assignEditMode == 5) {
        potMessages[selectedPot].isInverted = !potMessages[selectedPot].isInverted;
        drawAssignScreen();
      }
      lastButtonPressTime = currentTime;
    }
  }
  lastPrevButtonState = prevButtonState;

  // NEXT BUTTON
  if (nextButtonState == LOW && lastNextButtonState == HIGH) {
    if ((currentTime - lastButtonPressTime) > buttonDebounceDelay) {
      if (assignEditMode == 0) {
        selectedPot = (selectedPot + 1) % 8;
        drawAssignScreen();
      } else if (assignEditMode == 1) {
        if (potMessages[selectedPot].omni) {
          potMessages[selectedPot].omni = false;
          potMessages[selectedPot].channel = 1;
        } else {
          if (potMessages[selectedPot].channel < 16) {
            potMessages[selectedPot].channel++;
          } else {
            potMessages[selectedPot].omni = true;
          }
        }
        drawAssignScreen();
      } else if (assignEditMode == 2) {
        if (potMessages[selectedPot].cc < 127) {
          potMessages[selectedPot].cc++;
        } else {
          potMessages[selectedPot].cc = 0;
        }
        drawAssignScreen();
      } else if (assignEditMode == 3) {
        if (potMessages[selectedPot].minValue < 127) {
          potMessages[selectedPot].minValue++;
        } else {
          potMessages[selectedPot].minValue = 0;
        }
        drawAssignScreen();
      } else if (assignEditMode == 4) {
        if (potMessages[selectedPot].maxValue < 127) {
          potMessages[selectedPot].maxValue++;
        } else {
          potMessages[selectedPot].maxValue = 0;
        }
        drawAssignScreen();
      } else if (assignEditMode == 5) {
        potMessages[selectedPot].isInverted = !potMessages[selectedPot].isInverted;
        drawAssignScreen();
      }
      lastButtonPressTime = currentTime;
    }
  }
  lastNextButtonState = nextButtonState;
}
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
void loop() {
  unsigned long currentTime = millis();

  // Handle flashing for assign screen
  if (currentScreen == ASSIGN_SCREEN && assignEditMode == 0) {
    if ((currentTime - lastFlashTime) > flashInterval) {
      showPotNumber = !showPotNumber;
      drawAssignScreen();
      lastFlashTime = currentTime;
    }
  }

  // Read all pots on a single timer instead of 8 individual timers
  if ((currentTime - lastPotReadTime) >= readDelay) {
    lastPotReadTime = currentTime;

    // Read potentiometers 1-7 (pots 0-6)
    for (int pot = 0; pot < 7; pot++) {
      int rawValue = readMUXChannel(pot);
      int midiValue = mapRawToMIDI(pot, rawValue);

      if (catchupModeActive) continue;

      if (abs(midiValue - lastMidiValues[pot]) >= CHANGE_THRESHOLD) {
        lastRawValues[pot] = rawValue;
        lastMidiValues[pot] = midiValue;
        lastEditedPot = pot;
        if (currentScreen == MAIN_SCREEN) {
          sendMIDICC(pot, midiValue);
          drawMainScreen(lastEditedPot, midiValue);
        }
      }
    }

    // Handle Pot 8 specifically
    if (currentScreen == ASSIGN_SCREEN) {
      handlePot8Editing();
    } else {
      int rawValue = readMUXChannel(7);
      int midiValue = mapRawToMIDI(7, rawValue);
      if (!catchupModeActive && abs(midiValue - lastMidiValues[7]) >= CHANGE_THRESHOLD) {
        lastRawValues[7] = rawValue;
        lastMidiValues[7] = midiValue;
        lastEditedPot = 7;
        sendMIDICC(7, midiValue);
        drawMainScreen(7, midiValue);
      }
    }
  }

  // Handle catch-up mode and buttons every cycle regardless of pot read timer
  handleCatchup();
  readButtons();
}

// -- DISPLAY SCREENS --
void drawLoadingScreen() {

  display.clearDisplay();
  display.drawRoundRect(1, 1, 125, 62, 4, SSD1306_WHITE);
  display.setTextColor(SSD1306_WHITE);
  display.setTextSize(2);
  display.setCursor(41, 14);
  display.print(F("MC8P"));
  display.setTextSize(1);
  display.setCursor(53, 31);
  display.print(F("mini"));
  display.setCursor(55, 45);

  // -- NANO R3/R4 CHANGES
  //display.print(FIRMWARE_VERSION);                        // NANO R4
  display.print((__FlashStringHelper*)FIRMWARE_VERSION);  // USE WITH NANO R3
  // --

  display.display();
}

void drawMainScreen(int potNumber, int midiValue) {
  display.clearDisplay();
  display.drawRoundRect(1, 1, 125, 62, 4, SSD1306_WHITE);
  display.drawRoundRect(6, 47, 115, 10, 1, SSD1306_WHITE);

  int barWidth = map(midiValue, 0, 127, 0, 111);
  if (barWidth > 0) {
    display.fillRect(8, 49, barWidth, 6, SSD1306_WHITE);
  }

  display.setTextColor(SSD1306_WHITE);
  display.setTextSize(1);
  display.setCursor(50, 10);
  display.print(F("POT "));
  display.print(potNumber + 1);

  display.setTextSize(2);

  // Calculate horizontal center for the MIDI value
  // Text size 2 means each character is approximately 12 pixels wide (6x2 for width)
  // Get the number of digits in the MIDI value
  int numDigits;
  if (midiValue < 10) numDigits = 1;
  else if (midiValue < 100) numDigits = 2;
  else numDigits = 3;

  // Calculate starting X position to center the number
  // Screen width is 128, text width is roughly (numDigits * 12)
  int textWidth = numDigits * 12;
  int startX = (128 - textWidth) / 2;

  display.setCursor(startX, 27);
  display.print(midiValue);

  display.display();
}

void drawAssignScreen() {
  display.clearDisplay();
  display.setTextSize(1);

  display.drawRoundRect(1, 1, 125, 62, 4, SSD1306_WHITE);
  display.setTextColor(SSD1306_WHITE);

  // Title
  display.setCursor(8, 10);
  display.print(F("MIDI ASSIGN"));

  // Show current edit mode
  display.setCursor(8, 22);
  if (assignEditMode == 0) display.print(F("SELECT POT"));
  else if (assignEditMode == 1) display.print(F("EDIT CHANNEL"));
  else if (assignEditMode == 2) display.print(F("EDIT CC"));
  else if (assignEditMode == 3) display.print(F("EDIT MIN"));
  else if (assignEditMode == 4) display.print(F("EDIT MAX"));
  else display.print(F("EDIT DIR"));

  // Pot number
  display.setCursor(93, 10);
  if (assignEditMode == 0 && !showPotNumber) {
    display.print(F("     "));
  } else {
    display.print(F("POT "));
    display.print(selectedPot + 1);
  }

  // Channel display
  display.setCursor(8, 35);
  if (assignEditMode == 1) display.print(F("CH ["));
  else display.print(F("CH "));

  if (potMessages[selectedPot].omni) display.print(F("OMNI"));
  else display.print(potMessages[selectedPot].channel);

  if (assignEditMode == 1) display.print(F("]"));
  else display.print(F("   "));

  // CC display
  display.setCursor(8, 47);
  if (assignEditMode == 2) display.print(F("CC ["));
  else display.print(F("CC "));

  display.print(potMessages[selectedPot].cc);

  if (assignEditMode == 2) display.print(F("]"));
  else display.print(F("   "));

  // Range display
  display.setCursor(66, 35);
  if (assignEditMode == 3) display.print(F("MIN ["));
  else if (assignEditMode == 4) display.print(F("MAX ["));

  if (assignEditMode == 3) display.print(potMessages[selectedPot].minValue);
  else if (assignEditMode == 4) display.print(potMessages[selectedPot].maxValue);
  else {
    display.print(potMessages[selectedPot].minValue);
    display.print(F("-"));
    display.print(potMessages[selectedPot].maxValue);
  }

  if (assignEditMode == 3 || assignEditMode == 4) display.print(F("]"));

  // Direction display
  display.setCursor(66, 47);
  if (assignEditMode == 5) display.print(F("DIR ["));
  else display.print(F("DIR "));

  if (potMessages[selectedPot].isInverted) display.print(F("INV"));
  else display.print(F("NOR"));

  if (assignEditMode == 5) display.print(F("]"));

  display.display();
}

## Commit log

2026-04-16 production files
    [MC8P_MINI_KICAD.kicad_pcb, MC8P_MINI_KICAD.kicad_sch, MC8P_MINI_rev_1_bom.csv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]
2026-04-17 MIDI output fixed
    MIDI out for nano r4
    [MC8P_MINI_MIDICONTROLLER_FIRMWARE.ino]
2026-04-17 PCB & Schematic Updated
    Added pull up resistors with jumpers to work with Arduino nano r4
    [MC8P_MINI_KICAD.kicad_pcb, MC8P_MINI_KICAD.kicad_sch]
2026-04-18 PCB updated
    updated back side to indicate when jumper wires are used
    [MC8P_MINI_KICAD.kicad_pcb, MC8P_MINI_rev_1_bom.csv, MC8P_MINI_rev_1_positions.csv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]
2026-05-01 added ProMicro version
    Created ProMicro version for USB MIDI support
    [MC8P_MINI_KICAD.kicad_pcb, MC8P_MINI_KICAD_ProMicro.kicad_pcb, MC8P_MINI_KICAD_ProMicro.kicad_sch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]
2026-05-01 Pro Micro FW
    Added FW for Pro Micro Version
    - Adds USB MIDI
    [MC8P_MINI_KICAD_ProMicro.kicad_pcb]
2026-05-02 PCV Rev2
    replaced Nano version with Pro Micro
    [MC8P_MINI_KICAD.kicad_pcb, MC8P_MINI_KICAD.kicad_sch, MC8P_MINI_KICAD_ProMicro.kicad_pcb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]
2026-05-02 production files update
    [MC8P_MINI_KICAD.kicad_pcb, MC8P_MINI_ProMicro_rev_1_bom-JLCPCB Assembly Order.xls, MC8P_MINI_ProMicro_rev_1_positions.csv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]
2026-10-30 NANO firmware v1.1: stability and performance fixes, README update
    Firmware (NANO R3/R4):
    - Enable I2C bus timeout with automatic OLED re-init, so a glitched
    bus can no longer hang the loop
    - Rate-limit and batch OLED redraws (~25 fps cap)
    - Per-pot catch-up after temp mode: pots no longer lock until every
    pot is back, and caught-up pots stop resending CC/redrawing each loop
    - Raw-domain hysteresis: full 0-127 resolution without jitter
    - Per-button debounce; buttons read active-HIGH with INPUT to match
    the board's 10k pull-downs (INPUT_PULLUP left the idle level marginal)
    - Faster ADC with a throwaway read after each MUX switch
    - Shrink MIDI library SysEx buffer (~120 bytes RAM); free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
